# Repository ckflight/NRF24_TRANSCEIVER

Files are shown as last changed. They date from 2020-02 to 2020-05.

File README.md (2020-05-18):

# NRF24_TRANSCEIVER

This is a small board including KL27Z MCU, NRF24 2.4Ghz Transceiver IC and RFX2401C Front End with Power Amplifier for transmission and Low Noise Amplifier for reception.

A simple firmware for NRF24 usage with baremetal library implementation is included in firmware folder.

nrf24

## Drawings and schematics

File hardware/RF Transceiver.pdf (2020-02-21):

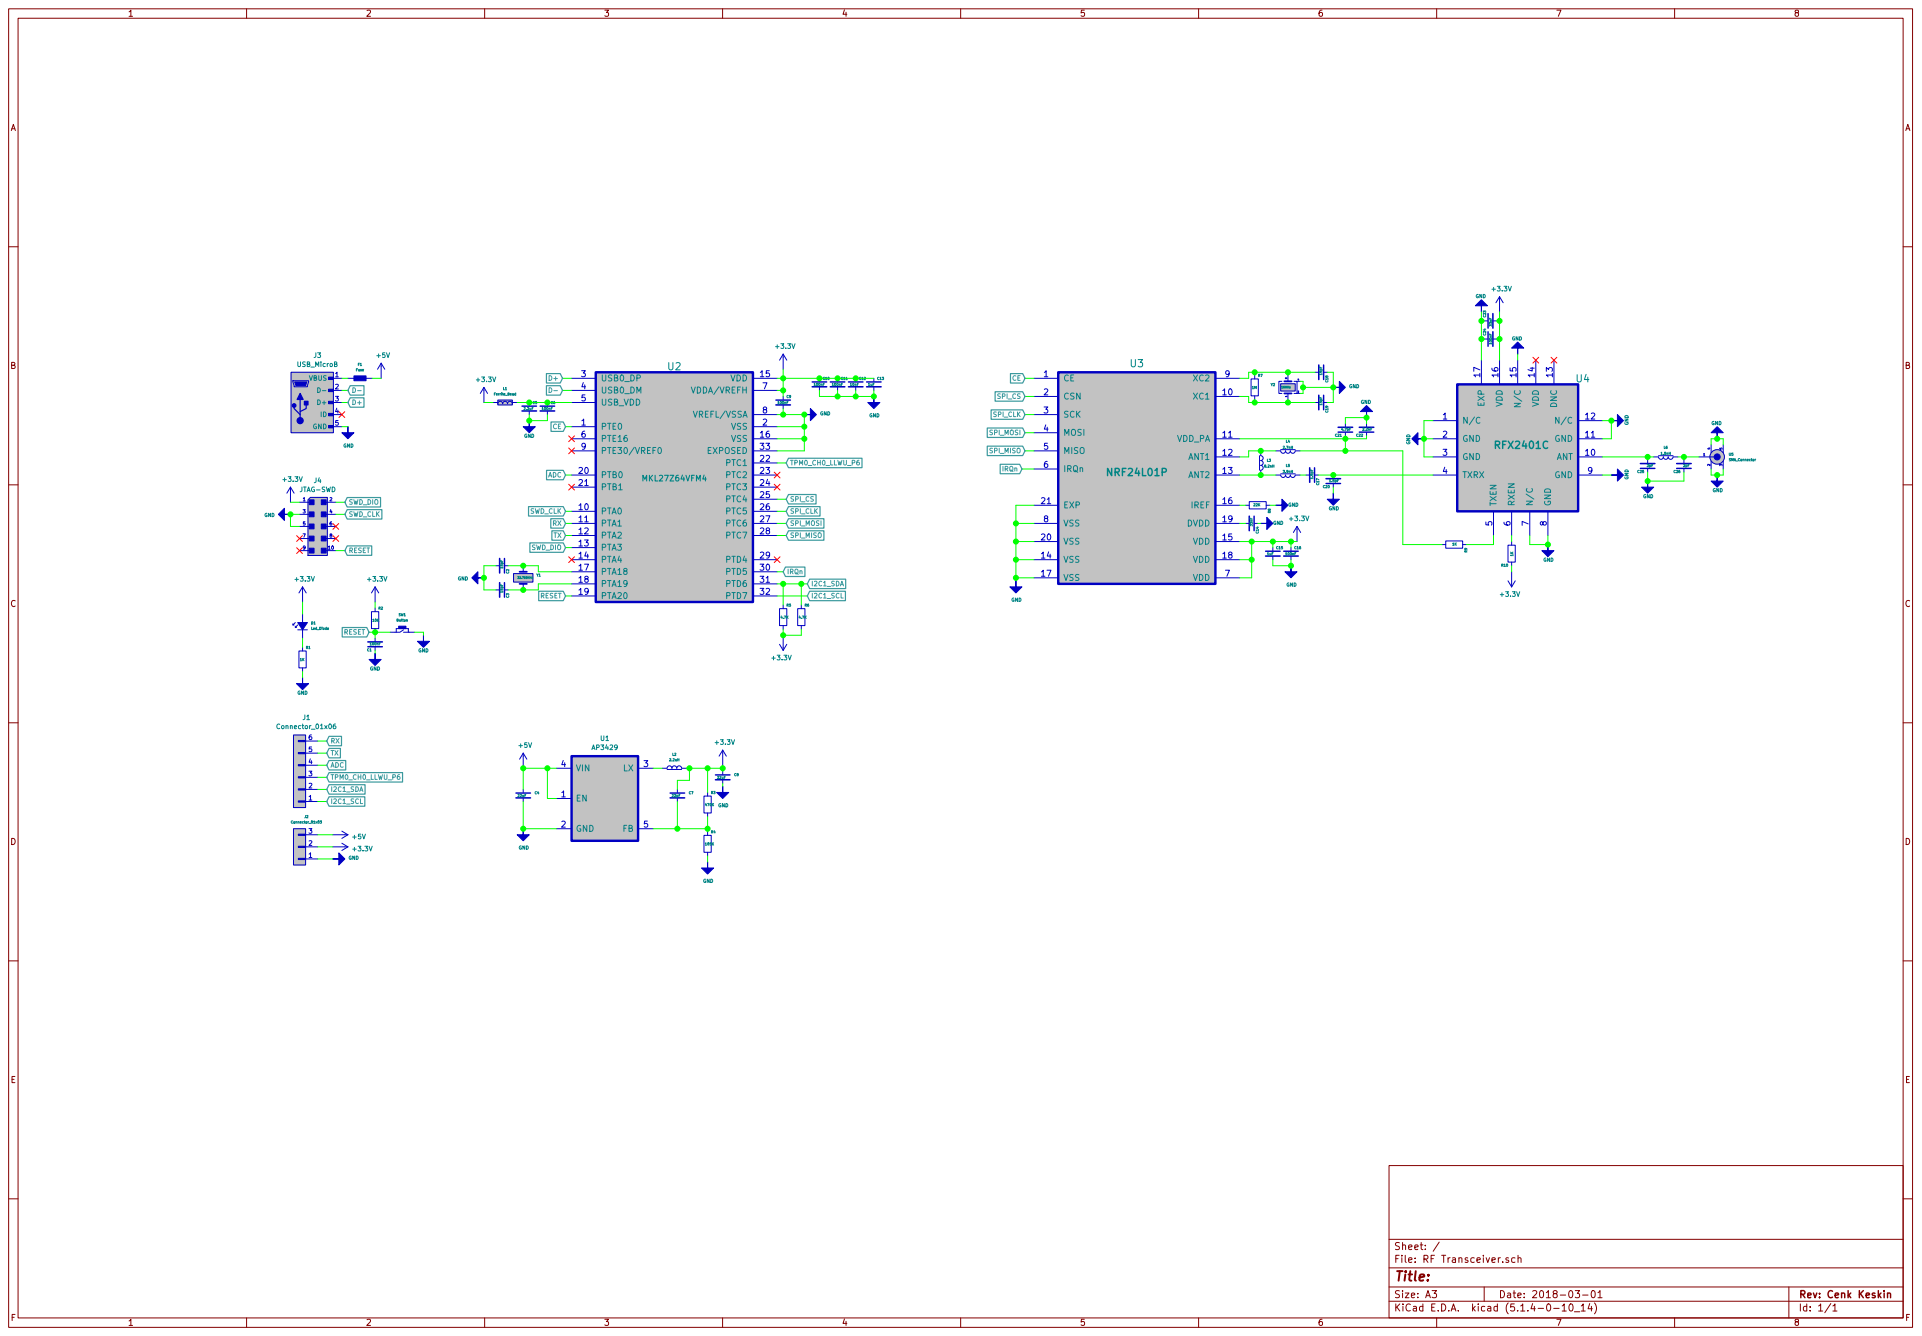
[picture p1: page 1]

8 GND 9 ANT 10 GND 11 N/C 12 DNC 13 VDD 14 N/C 15 VDD 16 EXP 17 U4 RFX2401C

Id: 1/1 Title: File: RF Transceiver.sch Sheet: /

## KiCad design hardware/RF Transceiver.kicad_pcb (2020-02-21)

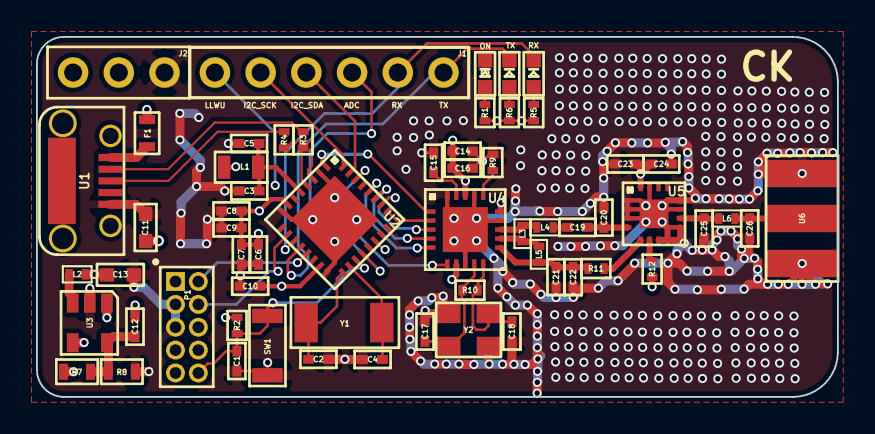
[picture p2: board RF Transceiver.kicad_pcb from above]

Board: 4 copper layers, 44.5 x 20.0 mm, 60 parts (0 on the bottom side), 44 nets.

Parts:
C1, C5, C7, C9, C10, C24: 0.1uF; C_0402
C2, C4, C17, C18: 15pF; C_0402
C3: 2.2uF; C_0402
C6, C8: 1uF; C_0402
C11, C13: 22uF; C_0603
C12: 22pF; C_0402
C14, C23: 10nF; C_0402
C15: 33nF; C_0402
C16: 1nF; C_0402
C19: 1.5pF; C_0402
C20: 1pF; C_0402
C21: 2.2nF; C_0402
C22: 4.7pF; C_0402
C25, C26: 2pF; C_0402
F1: Fuse_Small; R_0603
J1: GPIO; Pin_Header_Straight_1x06_Pitch2.54mm
J2: POWER; Pin_Header_Straight_1x03_Pitch2.54mm
L1: 330 Ohm; L_0805
L2: 2.2uH; L_0402
L3: 8.2nH; L_0402
L4: 3.9nH; L_0402
L5: 2.7nH; L_0402
L6: 1.5nH; L_0402
ON: LED_Small; LED_0603
P1: SWD/JTAG; Pin_Header_Straight_2x05_Pitch1.27mm
R1, R11, R12: 1K; R_0402
R2: 10K; R_0402
R3, R4, R5, R6: 33; R_0402
R7: 470K; R_0603
R8: 105K; R_0603
R9: 22K; R_0402
R10: 1M; R_0402
RX: LED_Small; LED_0603
SW1: RST_Button; B3U_Button
TX: LED_Small; LED_0603
U1: MICRO-USB-B; USB_MicroB-TH
U2: MKL27Z64VFM4; QFN32-1EXP_5x5mm_Pitch0.5mm
U3: AP3429AKTTR; SOT-23-5
U4: nRF24L01P-R7; QFN20-1EXP_4x4mm_Pitch0.5mm
U5: RFX2401C; QFN16-1EXP_3x3mm_Pitch0.5mm
U6: SMA_CONN
Y1: 32.768Khz
Y2: 16Mhz

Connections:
3.3V: C6.1, C7.1, C8.1, C9.1, C10.1, C12.1, C13.1, C14.1, C16.1, C23.1, C24.2, J2.2, L1.1, L2.2, P1.1, R1.2, R2.1, R5.2, R6.2, R7.1, R12.2, U2.7, U2.15, U4.7, U4.15, U4.18, U5.16
5V: C11.1, F1.2, J2.3, U3.1, U3.4
ADC: J1.3, U2.20
CE: U2.1, U4.1
CSN: U2.25, U4.2
GND: C1.2, C2.2, C3.2, C4.2, C5.2, C6.2, C7.2, C8.2, C9.2, C10.2, C11.2, C13.2, C14.2, C15.2, C16.2, C17.1, C18.1, C20.1, C21.2, C22.2, C23.2, C24.1, C25.2, C26.2, J2.1, ON.1, P1.3, P1.5, R8.2, R9.2, SW1.1, U1.5, U2.2, U2.8, U2.16, U2.33, U3.2, U4.8, U4.14, U4.17, U4.20, U4.21, U5.1, U5.2, U5.3, U5.7, U5.8, U5.9, U5.11, U5.12, U5.15, U5.17, U6.2, U6.3, U6.4, U6.5, Y2.2, Y2.4
I2C1_SCK: J1.5, U2.32
I2C1_SDA: J1.4, U2.31
IRQn: U2.30, U4.6
unnamed: C2.1, U2.17, Y1.2
unnamed: C4.1, U2.18, Y1.1
unnamed: C12.2, R7.2, R8.1, U3.5
unnamed: C15.1, U4.19
unnamed: C17.2, R10.1, U4.9, Y2.1
unnamed: C18.2, R10.2, U4.10, Y2.3
unnamed: C19.1, C20.2, U5.4
unnamed: C19.2, L4.2
unnamed: C21.1, C22.1, L5.2, R11.2, U4.11
unnamed: C25.1, L6.2, U5.10
unnamed: C26.1, L6.1, U6.1
unnamed: F1.1, U1.1
unnamed: L2.1, U3.3
unnamed: L3.1, L5.1, U4.12
unnamed: L3.2, L4.1, U4.13
unnamed: ON.2, R1.1
unnamed: R3.1, U1.2
unnamed: R4.1, U1.3
unnamed: R5.1, RX.2
unnamed: R6.1, TX.2
unnamed: R9.1, U4.16
unnamed: R11.1, U5.5
unnamed: R12.1, U5.6
RESET: C1.1, P1.10, R2.2, SW1.2, U2.19
RX: J1.2, RX.1, U2.11
SPI_MISO: U2.28, U4.5
SPI_MOSI: U2.27, U4.4
SPI_SCK: U2.26, U4.3
SWD_CLK: P1.4, U2.10
SWD_DIO: P1.2, U2.13
TPM0_CH0/LLWU_P6: J1.6, U2.22
TX: J1.1, TX.1, U2.12
USB_M: R3.2, U2.4
USB_P: R4.2, U2.3
USB_VDD: C3.1, C5.1, L1.2, U2.5

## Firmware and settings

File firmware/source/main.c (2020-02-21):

#include <stdio.h>
#include "board.h"
#include "pin_mux.h"
#include "clock_config.h"
#include "MKL27Z644.h"

#include "CK_SPI.h"
#include "CK_TIME.h"
#include "CK_NRF24.h"

int main(void) {

  	/* Init board hardware. */
    BOARD_InitBootPins();
    BOARD_InitBootClocks();
  	/* Init FSL debug console. */
    BOARD_InitDebugConsole();

    //Dataset:
	uint8_t dataset1[] = "11111111111111111111111111111111";
	uint8_t dataset2[] = "11111111111111111111111111111111";

    CK_NRF24_Init();//Default Channel 100
    CK_NRF_SetChannelNumber(2);

    while(1){
    	CK_NRF24_SendMessage(dataset1);
    	CK_delayMs(25);
    	CK_NRF24_SendMessage(dataset2);
		CK_delayMs(25);
    }

}

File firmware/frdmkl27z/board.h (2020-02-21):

/*
 * Copyright (c) 2015, Freescale Semiconductor, Inc.
 * Copyright 2016-2017 NXP
 *
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
 * o Neither the name of the copyright holder nor the names of its
 *   contributors may be used to endorse or promote products derived from this
 *   software without specific prior written permission.
 *
 * THIS SOFTWARE IS PROVIDED BY THE COPYRIGHT HOLDERS AND CONTRIBUTORS "AS IS" AND
 * ANY EXPRESS OR IMPLIED WARRANTIES, INCLUDING, BUT NOT LIMITED TO, THE IMPLIED
 * WARRANTIES OF MERCHANTABILITY AND FITNESS FOR A PARTICULAR PURPOSE ARE
 * DISCLAIMED. IN NO EVENT SHALL THE COPYRIGHT HOLDER OR CONTRIBUTORS BE LIABLE FOR
 * ANY DIRECT, INDIRECT, INCIDENTAL, SPECIAL, EXEMPLARY, OR CONSEQUENTIAL DAMAGES
 * (INCLUDING, BUT NOT LIMITED TO, PROCUREMENT OF SUBSTITUTE GOODS OR SERVICES;
 * LOSS OF USE, DATA, OR PROFITS; OR BUSINESS INTERRUPTION) HOWEVER CAUSED AND ON
 * ANY THEORY OF LIABILITY, WHETHER IN CONTRACT, STRICT LIABILITY, OR TORT
 * (INCLUDING NEGLIGENCE OR OTHERWISE) ARISING IN ANY WAY OUT OF THE USE OF THIS
 * SOFTWARE, EVEN IF ADVISED OF THE POSSIBILITY OF SUCH DAMAGE.
 */

#ifndef _BOARD_H_
#define _BOARD_H_

#include "clock_config.h"
#include "fsl_gpio.h"

/*******************************************************************************
 * Definitions
 ******************************************************************************/

/* The board name */
#define BOARD_NAME "FRDM-KL27Z"

/* The LPUART to use for debug messages. */
#define BOARD_DEBUG_UART_TYPE DEBUG_CONSOLE_DEVICE_TYPE_LPUART
#define BOARD_DEBUG_UART_BASEADDR (uint32_t) LPUART0
#define BOARD_DEBUG_UART_CLKSRC kCLOCK_McgIrc48MClk
#define BOARD_DEBUG_UART_CLK_FREQ CLOCK_GetPeriphClkFreq()
#define BOARD_UART_IRQ LPUART0_IRQn
#define BOARD_UART_IRQ_HANDLER LPUART0_IRQHandler

#ifndef BOARD_DEBUG_UART_BAUDRATE
#define BOARD_DEBUG_UART_BAUDRATE 115200
#endif /* BOARD_DEBUG_UART_BAUDRATE */

/* Board led color mapping */
#define LOGIC_LED_ON 0U
#define LOGIC_LED_OFF 1U
#define BOARD_LED_RED_GPIO GPIOB
#define BOARD_LED_RED_GPIO_PORT PORTB
#define BOARD_LED_RED_GPIO_PIN 18U
#define BOARD_LED_GREEN_GPIO GPIOB
#define BOARD_LED_GREEN_GPIO_PORT PORTB
#define BOARD_LED_GREEN_GPIO_PIN 19U
#define BOARD_LED_BLUE_GPIO GPIOA
#define BOARD_LED_BLUE_GPIO_PORT PORTA
#define BOARD_LED_BLUE_GPIO_PIN 13U

#define LED_RED_INIT(output)                                                 \
    GPIO_WritePinOutput(BOARD_LED_RED_GPIO, BOARD_LED_RED_GPIO_PIN, output); \
    BOARD_LED_RED_GPIO->PDDR |= (1U << BOARD_LED_RED_GPIO_PIN) /*!< Enable target LED_RED */
#define LED_RED_ON() \
    GPIO_ClearPinsOutput(BOARD_LED_RED_GPIO, 1U << BOARD_LED_RED_GPIO_PIN) /*!< Turn on target LED_RED */
#define LED_RED_OFF() \
    GPIO_SetPinsOutput(BOARD_LED_RED_GPIO, 1U << BOARD_LED_RED_GPIO_PIN) /*!< Turn off target LED_RED */
#define LED_RED_TOGGLE() \
    GPIO_TogglePinsOutput(BOARD_LED_RED_GPIO, 1U << BOARD_LED_RED_GPIO_PIN) /*!< Toggle on target LED_RED */

#define LED_GREEN_INIT(output)                                                   \
    GPIO_WritePinOutput(BOARD_LED_GREEN_GPIO, BOARD_LED_GREEN_GPIO_PIN, output); \
    BOARD_LED_GREEN_GPIO->PDDR |= (1U << BOARD_LED_GREEN_GPIO_PIN) /*!< Enable target LED_GREEN */
#define LED_GREEN_ON() \
    GPIO_ClearPinsOutput(BOARD_LED_GREEN_GPIO, 1U << BOARD_LED_GREEN_GPIO_PIN) /*!< Turn on target LED_GREEN */
#define LED_GREEN_OFF() \
    GPIO_SetPinsOutput(BOARD_LED_GREEN_GPIO, 1U << BOARD_LED_GREEN_GPIO_PIN) /*!< Turn off target LED_GREEN */
#define LED_GREEN_TOGGLE() \
    GPIO_TogglePinsOutput(BOARD_LED_GREEN_GPIO, 1U << BOARD_LED_GREEN_GPIO_PIN) /*!< Toggle on target LED_GREEN */

#define LED_BLUE_INIT(output)                                                  \
    GPIO_WritePinOutput(BOARD_LED_BLUE_GPIO, BOARD_LED_BLUE_GPIO_PIN, output); \
    BOARD_LED_BLUE_GPIO->PDDR |= (1U << BOARD_LED_BLUE_GPIO_PIN) /*!< Enable target LED_BLUE */
#define LED_BLUE_ON() \
    GPIO_ClearPinsOutput(BOARD_LED_BLUE_GPIO, 1U << BOARD_LED_BLUE_GPIO_PIN) /*!< Turn on target LED_BLUE */
#define LED_BLUE_OFF() \
    GPIO_SetPinsOutput(BOARD_LED_BLUE_GPIO, 1U << BOARD_LED_BLUE_GPIO_PIN) /*!< Turn off target LED_BLUE */
#define LED_BLUE_TOGGLE() \
    GPIO_TogglePinsOutput(BOARD_LED_BLUE_GPIO, 1U << BOARD_LED_BLUE_GPIO_PIN) /*!< Toggle on target LED_BLUE */

#define BOARD_ACCEL_I2C_BASEADDR I2C1

/* ERPC SPI configuration */
#define ERPC_BOARD_SPI_BASEADDR SPI0
#define ERPC_BOARD_SPI_BAUDRATE 500000U
#define ERPC_BOARD_SPI_CLKSRC SPI0_CLK_SRC
#define ERPC_BOARD_SPI_CLK_FREQ CLOCK_GetFreq(SPI0_CLK_SRC)
#define ERPC_BOARD_SPI_INT_GPIO GPIOB
#define ERPC_BOARD_SPI_INT_PORT PORTB
#define ERPC_BOARD_SPI_INT_PIN 0U
#define ERPC_BOARD_SPI_INT_PIN_IRQ PORTB_PORTC_PORTD_PORTE_IRQn
#define ERPC_BOARD_SPI_INT_PIN_IRQ_HANDLER PORTB_PORTC_PORTD_PORTE_IRQHandler

/* Board accelerometer driver */
#define BOARD_ACCEL_MMA

#if defined(__cplusplus)
extern "C" {
#endif /* __cplusplus */
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
